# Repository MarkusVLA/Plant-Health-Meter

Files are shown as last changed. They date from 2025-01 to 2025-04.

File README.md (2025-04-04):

## Plant-health-meter
This repository contains Aalto AAN-C2009 project device hardware configuration and embedded software for a plant health monitoring system based on the ESP32c3 SoC.

## Features
- Soil moisture sensing
- Ambient light monitoring
- Temperature and humidity measurement
- Battery-powered operation with charging circuit
- Web interface for monitoring plant health 

## PCB
PCB design done in KiCad.
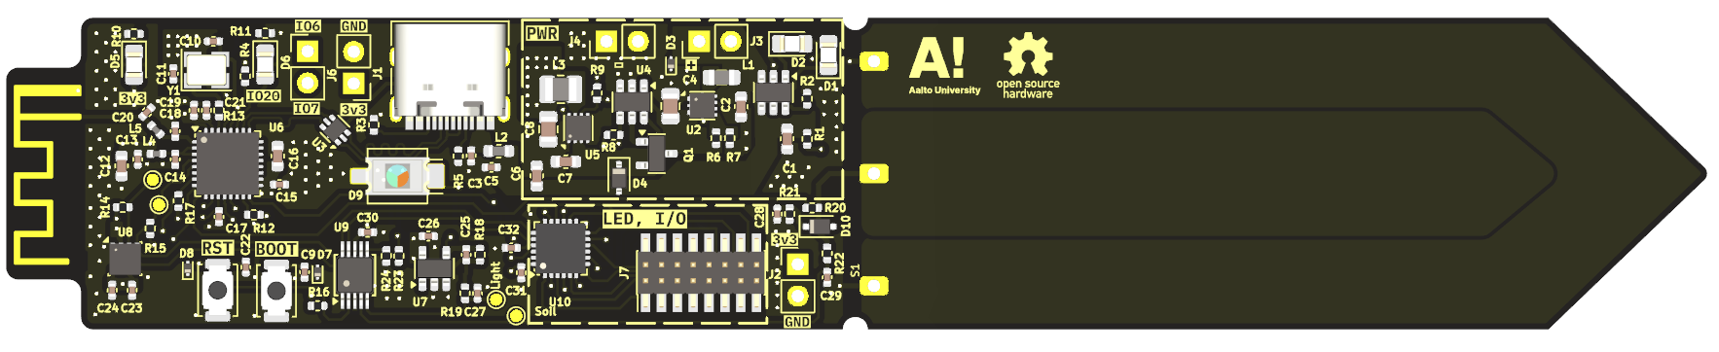
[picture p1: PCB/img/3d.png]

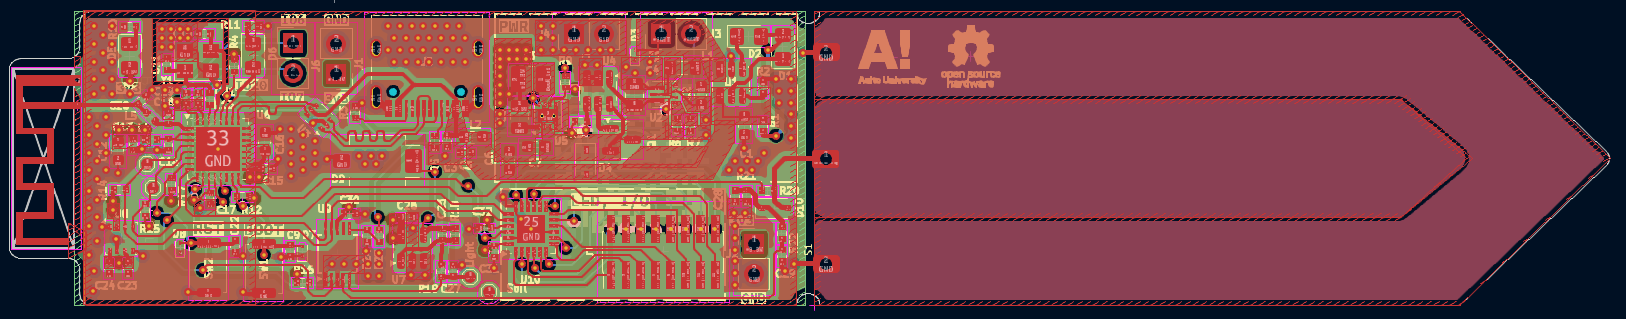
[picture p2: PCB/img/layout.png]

Schematic: [PDF](PCB/img/schematic.pdf)

## Key Components
- ESP32-C3 microcontroller
- BME280 temperature/humidity sensor
- Custom capacitive soil moisture sensor
- Photodiode and OPA340 based transimpedance amplifier
- ADS1115 16-bit ADC for accurate measurements

## Embedded software
Embedded software is written in C using the ESP-IDF (Espressif IoT Development Framework)
[ESP programming guide](https://docs.espressif.com/projects/esp-idf/en/v5.2.5/esp32c3/get-started/index.html)

## Pin Assignments
See the schematic for detailed I/O connections and sensor bus configuration.

## Setup Instructions
1. Follow the ESP-IDF installation guide
2. Clone this repository
3. In the `main/` folder create `private_config.h` file, with following definitions:
    1. `#define FIREBASE_HOST "xxx.firebasedatabase.app"` - url of the firebase realtime database
    2. `#define FIREBASE_AUTH ""` - authentication token for the firebase - (TODO: not tested yet with protected database)
4. Set ESP32-C3 target in the idf `idf.py set-target esp32c3`
5. Configure the partitions and BLE version `idf.py menuconfig`:
    1. Go to Partition Table → Partition Table and select Custom partition table CSV. Then set the path to `partitions.csv`.
    2. Go to Component Config → Bluetooth → Bluedroid BLE version and choose v4.0.
    3. Save and exit the configuration menu.
6. Build and flash using `idf.py build flash monitor`

## Connection Instructions

1. By default, there are no Wi-Fi credentials set. The device will immediately enter Bluetooth setup mode on boot.

2. For setup, you’ll need a mobile app capable of sending data over BLE, such as **nRF Connect**.

3. When the device is in Bluetooth setup mode, one of its LEDs will begin blinking. You can then find the device in the app under the name:  
   **`PLANT_SENSOR_01`**

4. Press **Connect** to establish a Bluetooth connection.

5. Once connected, look for **Advertised Services** in the device details. Find the characteristic that supports both **Read** and **Write**, and tap the **up arrow (⬆️)** to write data.

6. Select **UTF-8** as the encoding format and send a message with the following structure:  
   ```
   device_id:wifi_ssid:wifi_password
   ```

   For example:  
   ```
   sensor1:mywifi:secret_password
   ```

7. After sending the credentials, the device will restart and attempt to connect to the specified Wi-Fi network.

8. Once connected, sensor data will be sent to Firebase under the provided `device_id`.

---

**Important Notes:**
- `device_id` can contain only **letters, digits, and underscores** (e.g., `plant_sensor_1`).
- If the device fails to connect to Wi-Fi, it will re-enter Bluetooth setup mode on reboot.

## Power Requirements
3.7V Li-ion battery or USB power

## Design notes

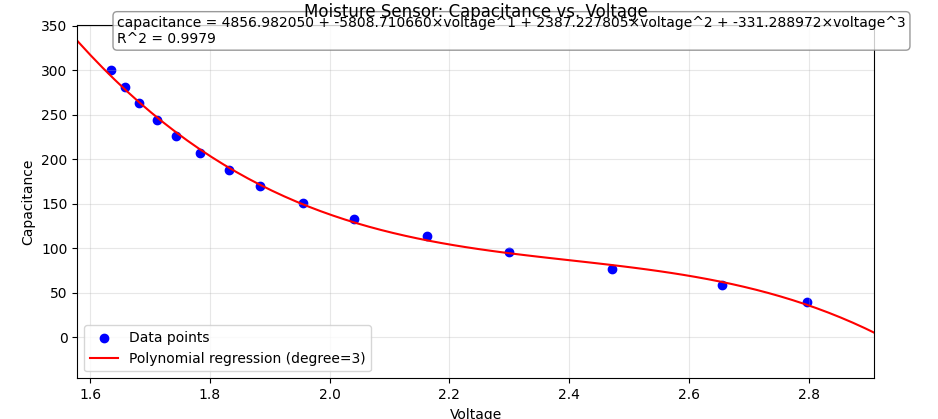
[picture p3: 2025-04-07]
documentation/img/regression.png

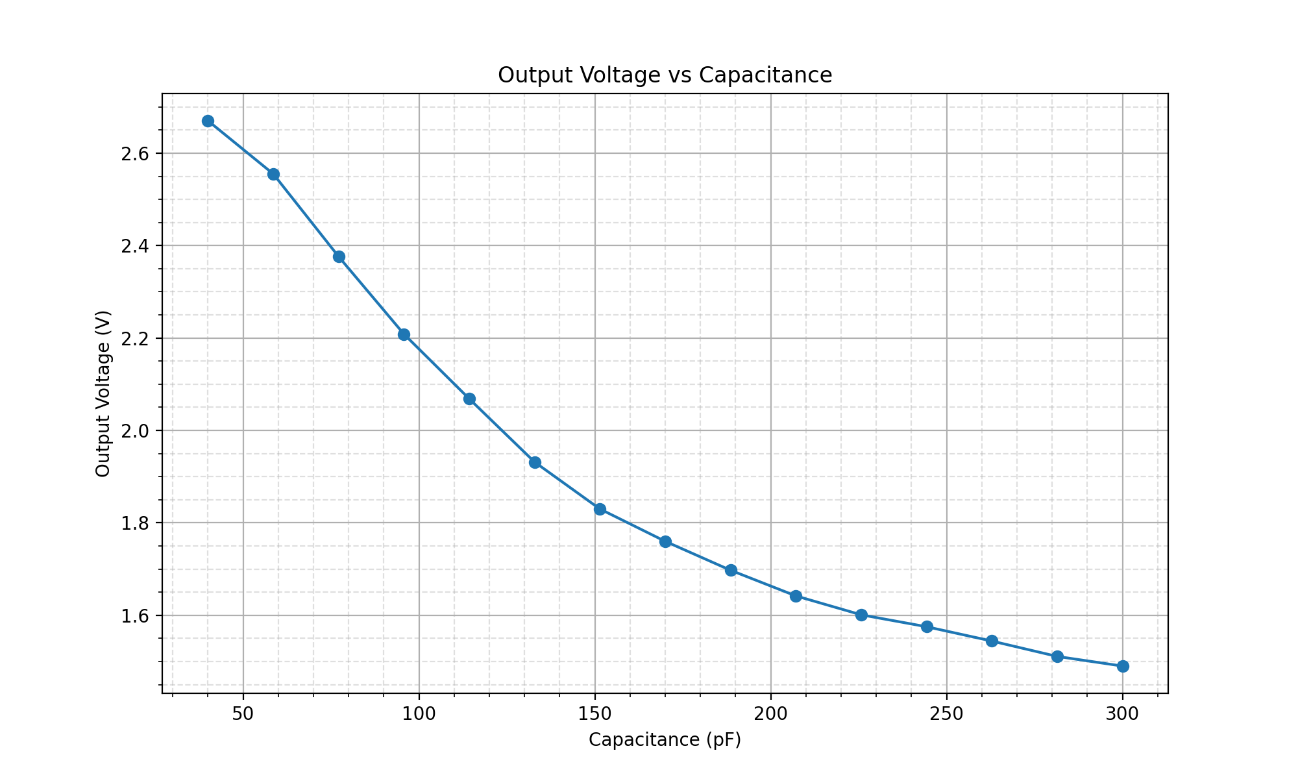
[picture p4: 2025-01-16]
simulation/Moisture_sensor/voltage_vs_capacitance.png

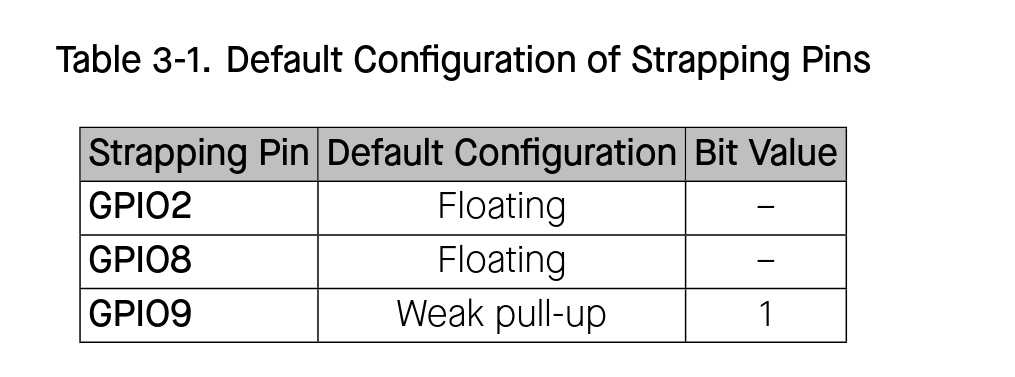
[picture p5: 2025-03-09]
PCB/Strapping_pins.png

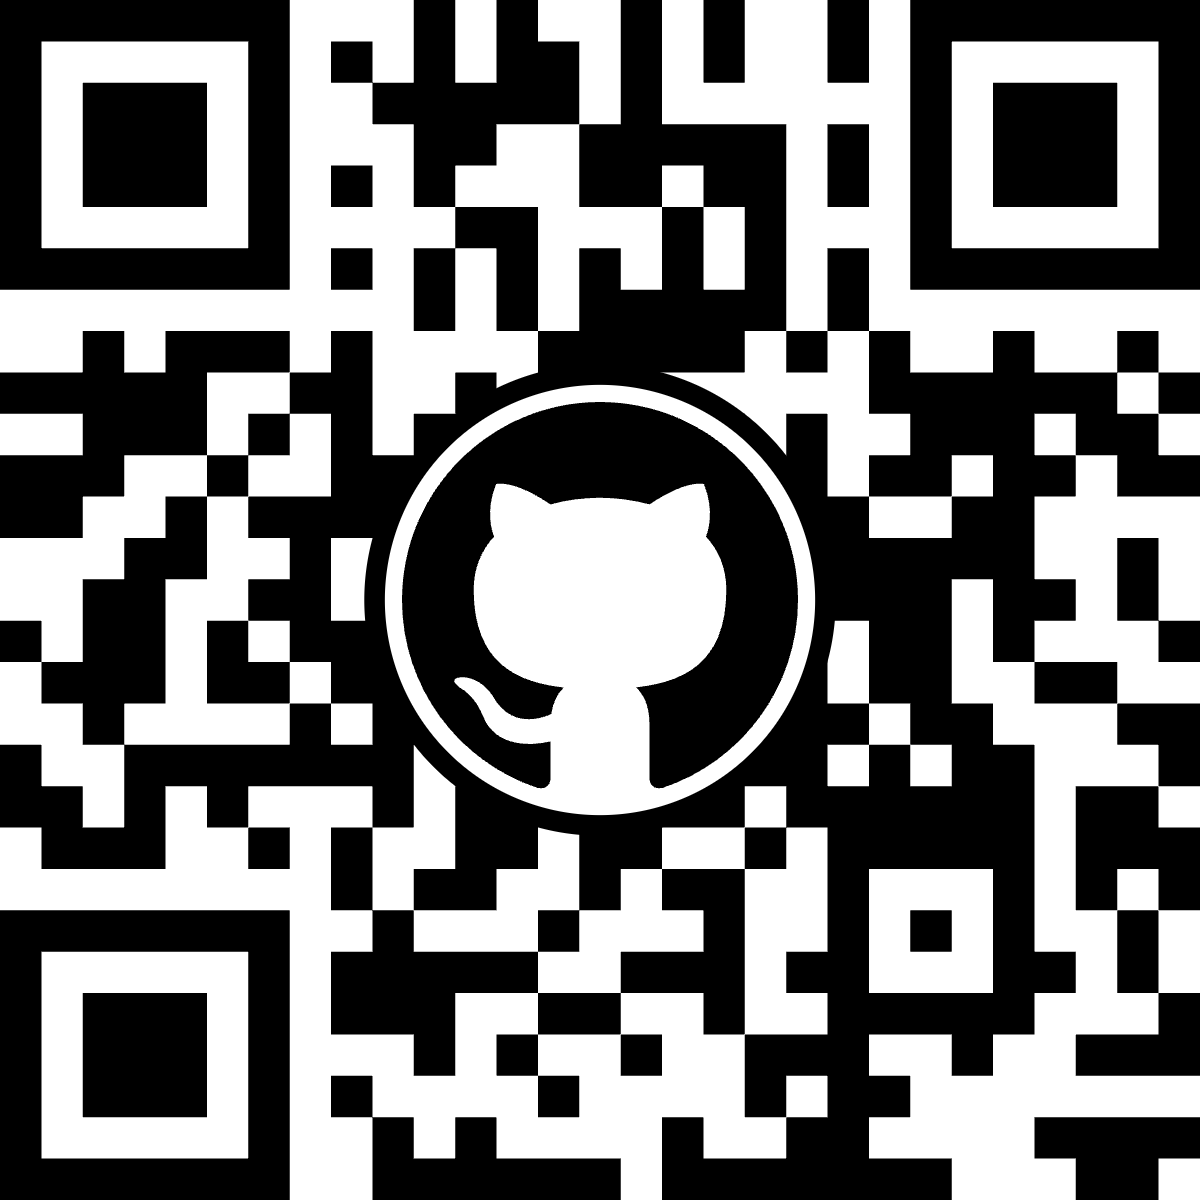
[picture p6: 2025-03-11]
PCB/silkscreen-pictures/QR-for-MarkusVLA.png

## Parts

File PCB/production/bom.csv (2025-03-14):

Designator | Footprint | Quantity | Value | LCSC Part #
AE1 | Texas_SWRA117D_2.4GHz_Left | 1 | Antenna_Shield
C1, C12, C16, C2, C6, C7 | 0603 | 6 | 10u
C10, C11 | 0402 | 2 | 15p
C13, C14, C15, C17, C19, C21, C22, C23, C24, C26, C27, C29, C3, C30, C31, C32, C5, C9 | 0402 | 18 | 100n
C18, C20 | 0402 | 2 | 2.2p
C25 | 0402 | 1 | 220n
C28 | 0402 | 1 | 1n
C4, C8 | 0805 | 2 | 22u
D1, D2, D5, D6 | 0805 | 4 | LED | C205445
D10 | D_SOD-323F | 1 | BAT54J
D3, D7, D8 | D_SOD-923 | 3 | ESD9B5.0ST5G
D4 | D_SOD-323 | 1 | BAT60A
D9 | Osram_BPW34S-SMD | 1 | BPW34-SMD
J1, J2, J3, J4, J6 | PinHeader_1x02_P2.54mm_Vertical | 5 | Conn_01x02
J5 | USB_C_Receptacle_HRO_TYPE-C-31-M-12 | 1 | USB_C_Receptacle_USB2.0_14P
J7 | PinHeader_2x08_P1.27mm_Vertical_SMD | 1 | Conn_02x08_Counter_Clockwise
L1 | 0805 | 1 | 1u
L2 | 0603 | 1 | 2.2n
L3 | 1008 | 1 | 2.2u
L4 | 0402 | 1 | 2.2n
L5 | 0402 | 1 | 2.6n
Q1 | SOT-23 | 1 | AO3401A
R1 | 0402 | 1 | 1k
R10, R11 | 0402 | 2 | 1k
R12, R14, R15, R16, R17, R2, R3, R5 | 0402 | 8 | 5.1k
R13 | 0402 | 1 | 10
R18 | 0402 | 1 | 33k
R19, R22 | 0402 | 2 | 510
R20, R4 | 0402 | 2 | 10k
R21 | 0402 | 1 | 1M
R23, R24, R7, R9 | 0402 | 4 | 100k
R6 | 0402 | 1 | 570k
R8 | 0402 | 1 | 470k
S1 | Moisture_sensor_pads | 1 | ~
SW1 | SW_Push_SPST_NO_Alps_SKRK | 1 | Boot | C115357
SW2 | SW_Push_SPST_NO_Alps_SKRK | 1 | Reset | C115357
TP1, TP2, TP3, TP4 | TestPoint_Pad_D1.0mm | 4 | TestPoint
U1 | TSOT-23-6 | 1 | TP4057
U10 | WQFN-24-1EP_4x4mm_P0.5mm_EP2.45x2.45mm | 1 | TCA9555RTWR
U2 | Texas_RWU0007A_VQFN-7_2x2mm_P0.5mm | 1 | TPS61022
U3 | SOT-666 | 1 | USBLC6-2P6
U4 | TSOT-23-6 | 1 | LTC4412xS6
U5 | WSON-8-1EP_2x2mm_P0.5mm_EP0.9x1.6mm_ThermalVias | 1 | TPS62172DSG
U6 | QFN-32-1EP_5x5mm_P0.5mm_EP3.7x3.7mm | 1 | ESP32-C3FH4X
U7 | SOT-23-5 | 1 | OPA340NA
U8 | Bosch_LGA-8_2.5x2.5mm_P0.65mm_ClockwisePinNumbering | 1 | BME280
U9 | TSSOP-10_3x3mm_P0.5mm | 1 | ADS1115IDGS
Y1 | Crystal_SMD_3225-4Pin_3.2x2.5mm | 1 | 40MHz

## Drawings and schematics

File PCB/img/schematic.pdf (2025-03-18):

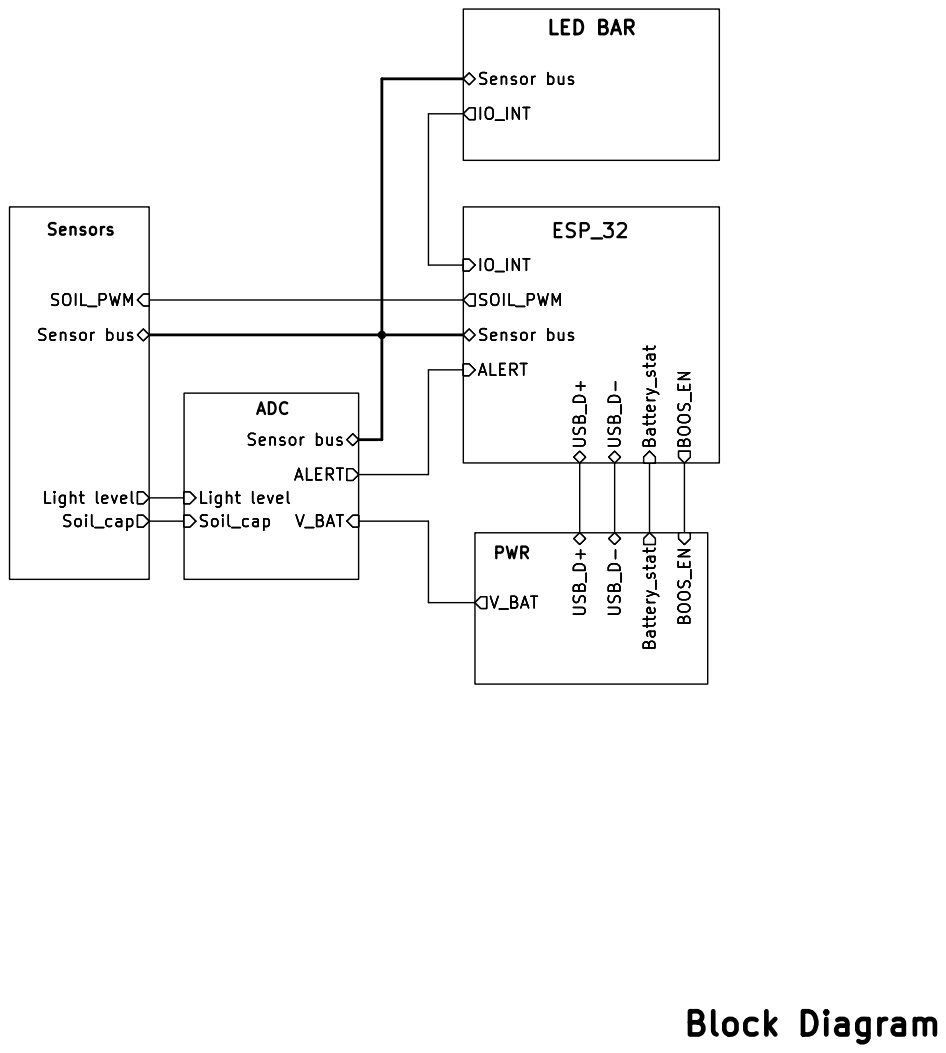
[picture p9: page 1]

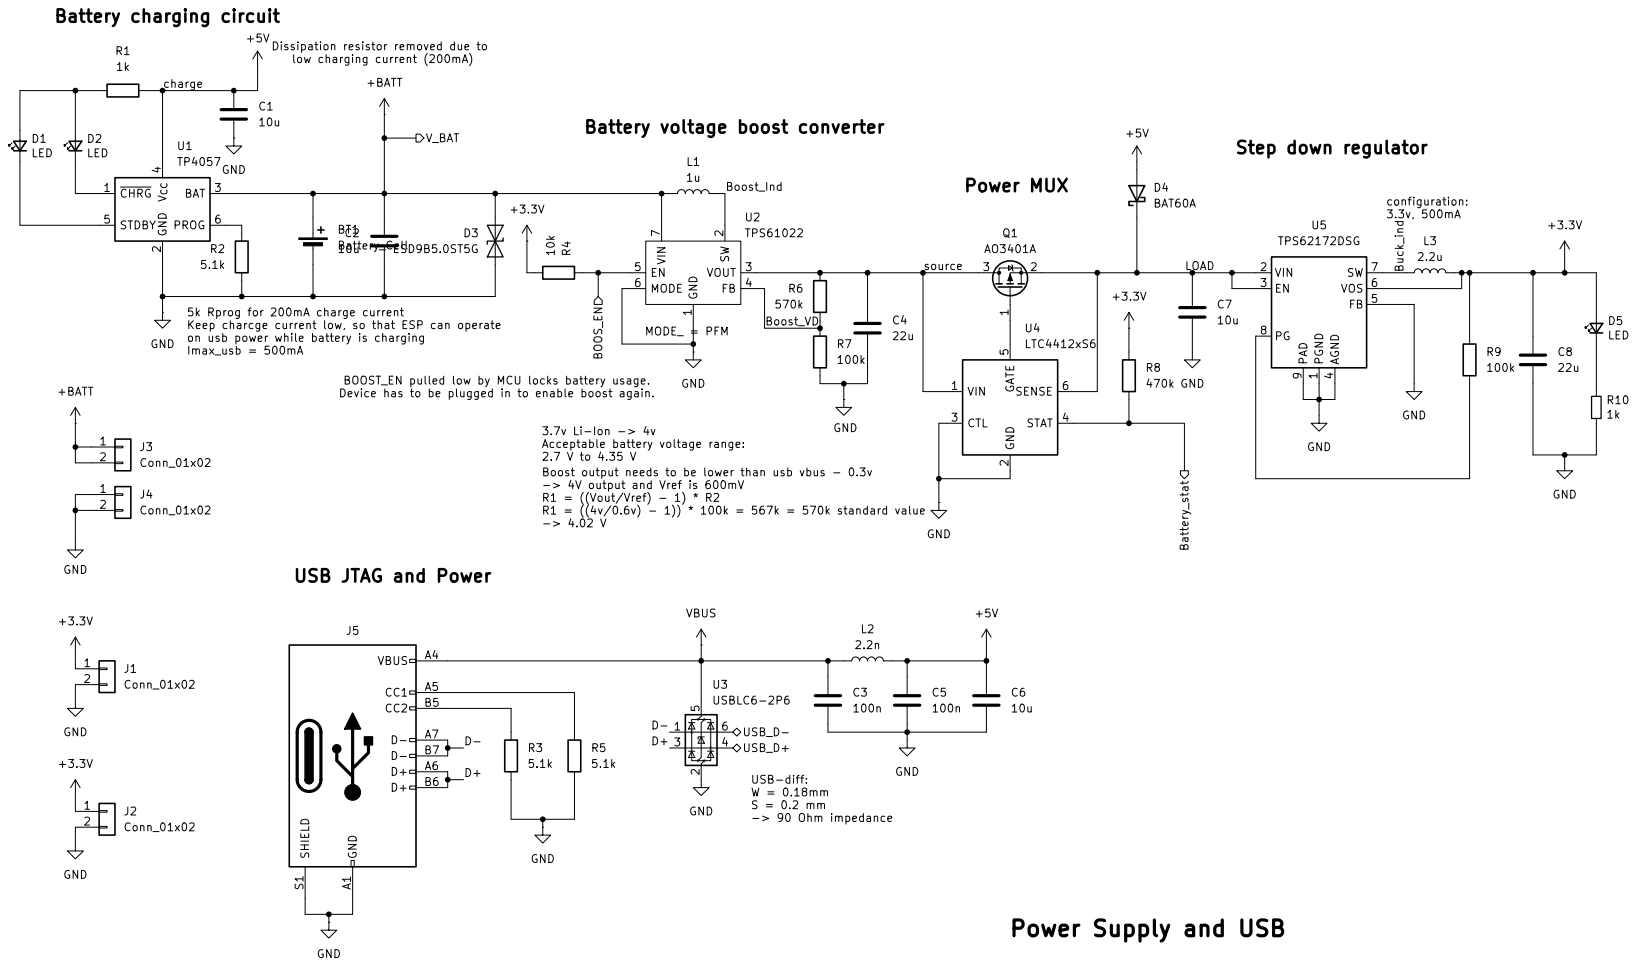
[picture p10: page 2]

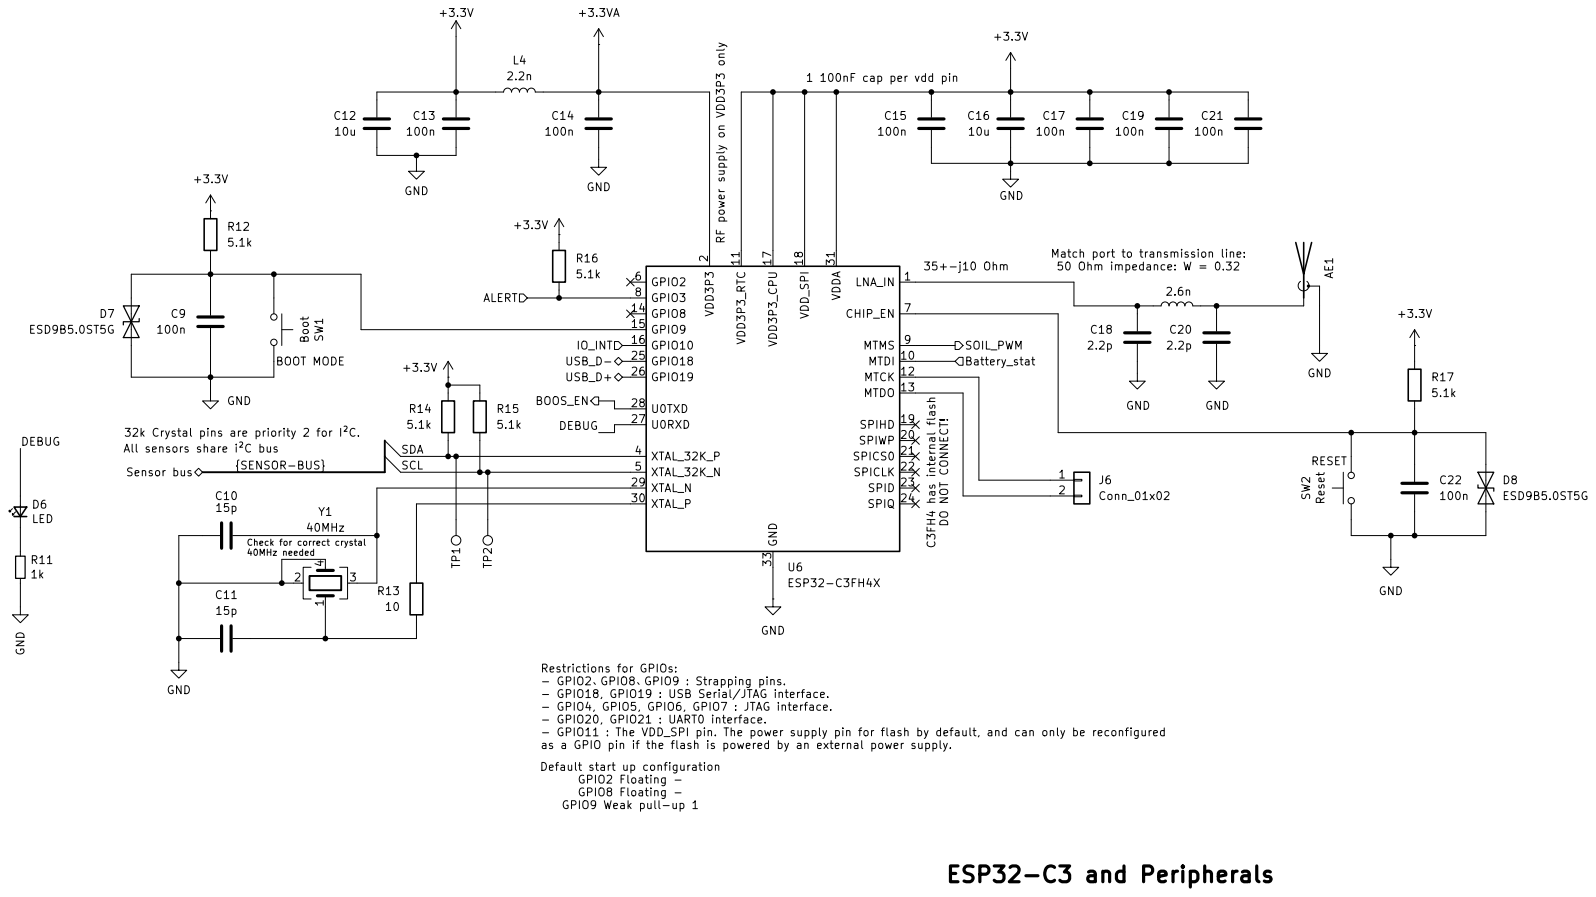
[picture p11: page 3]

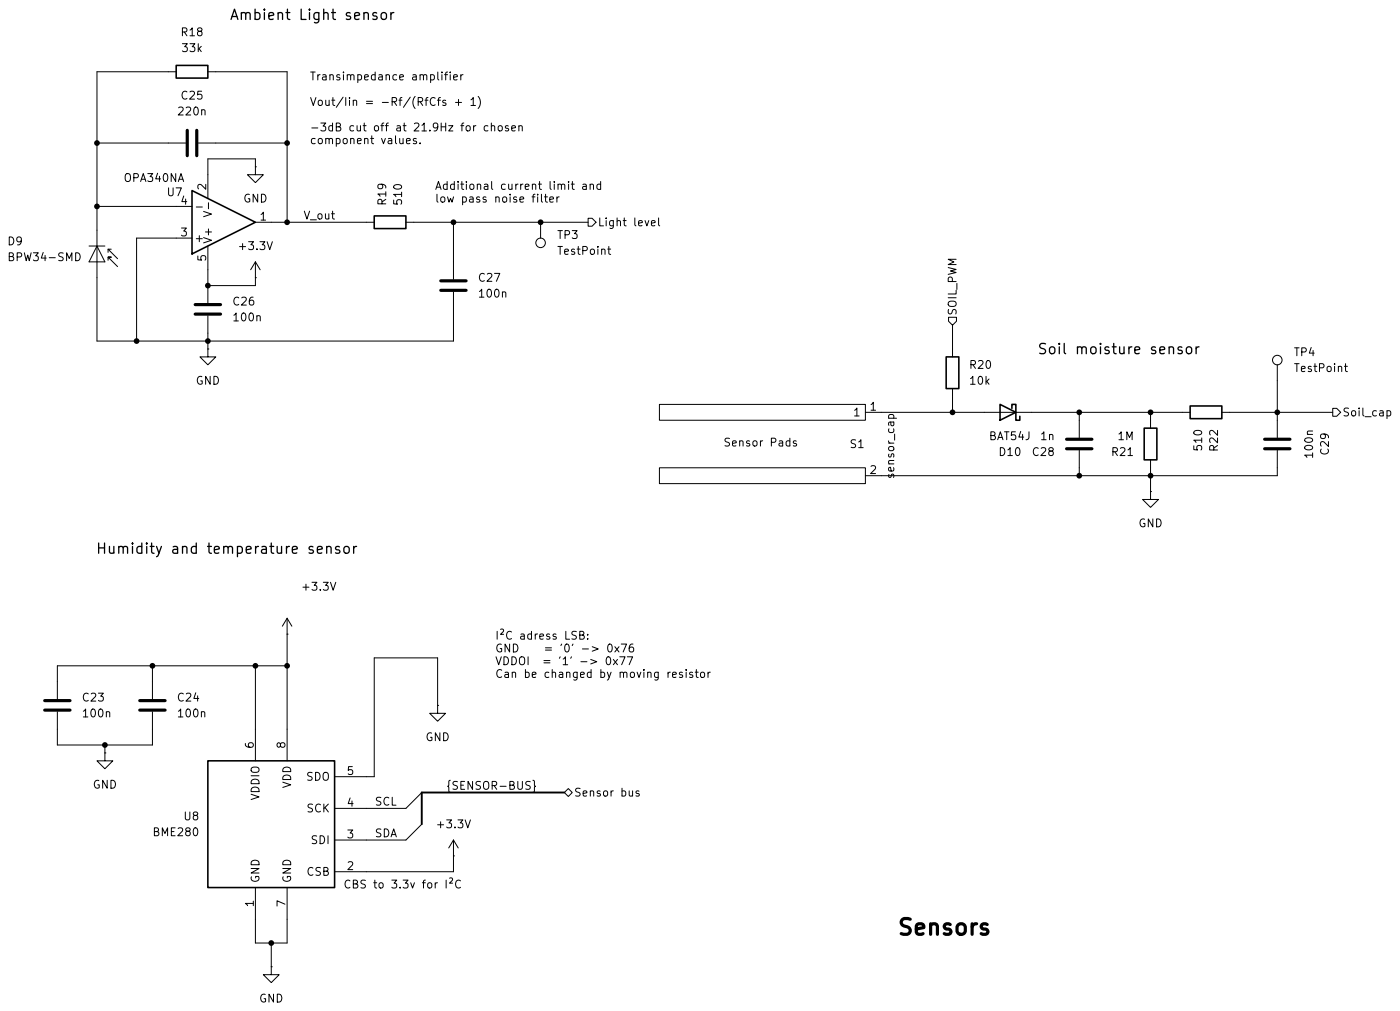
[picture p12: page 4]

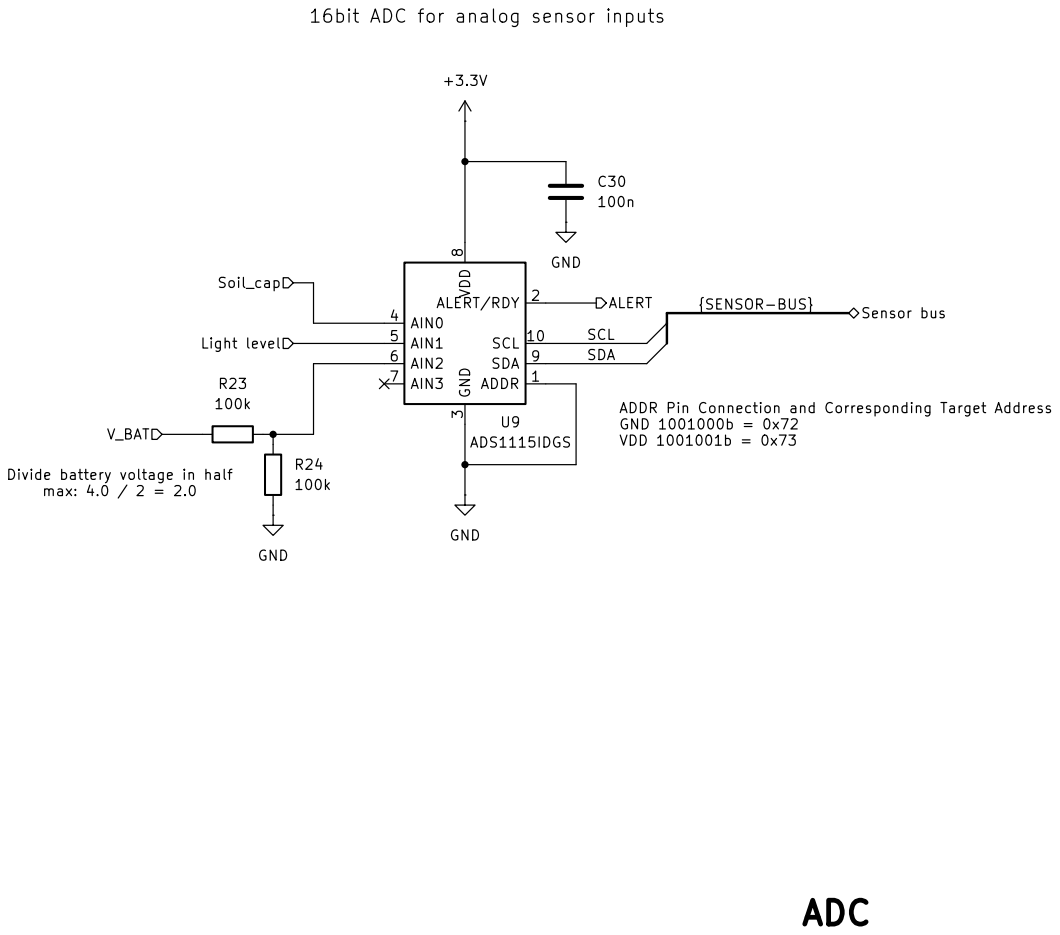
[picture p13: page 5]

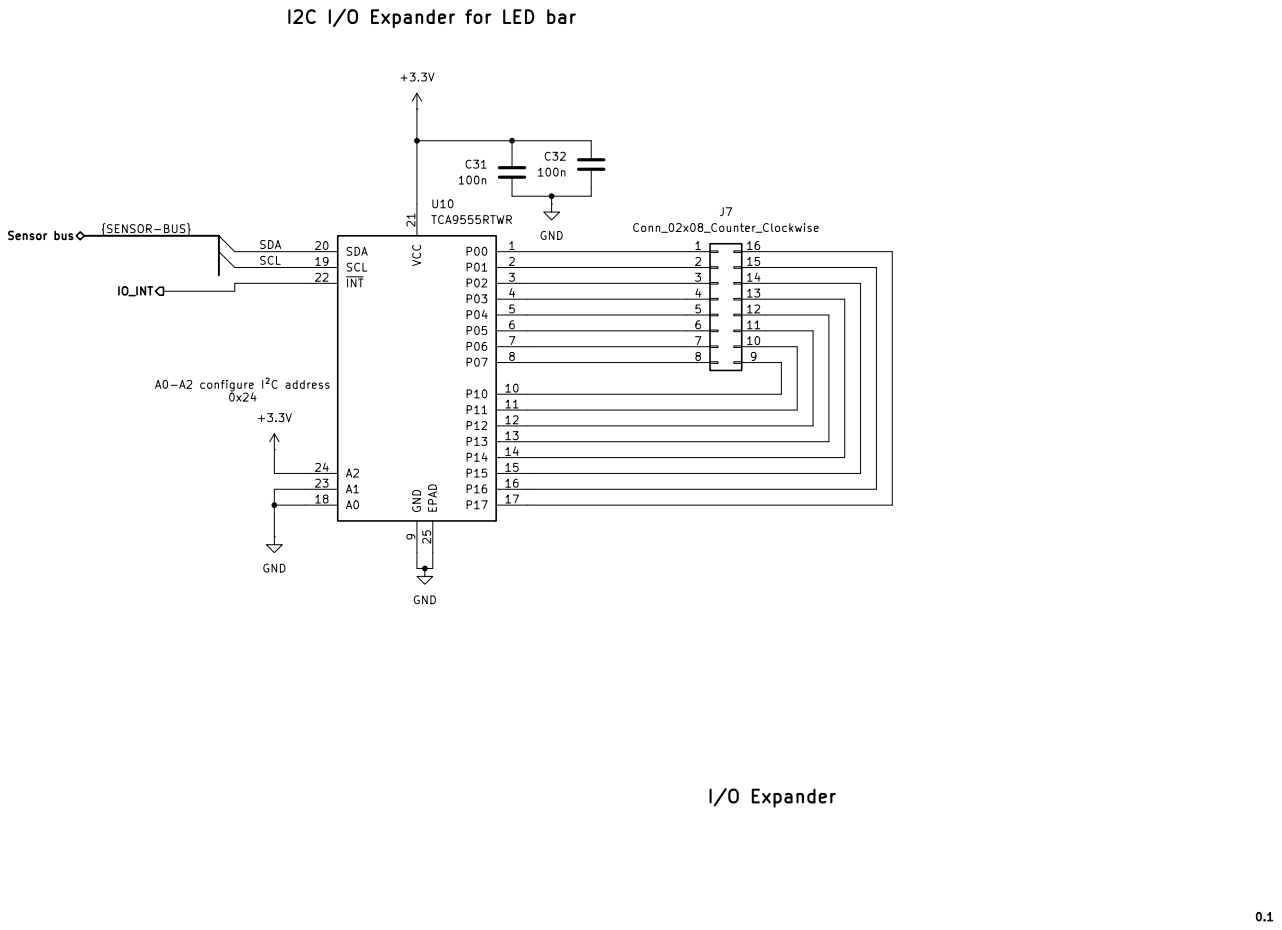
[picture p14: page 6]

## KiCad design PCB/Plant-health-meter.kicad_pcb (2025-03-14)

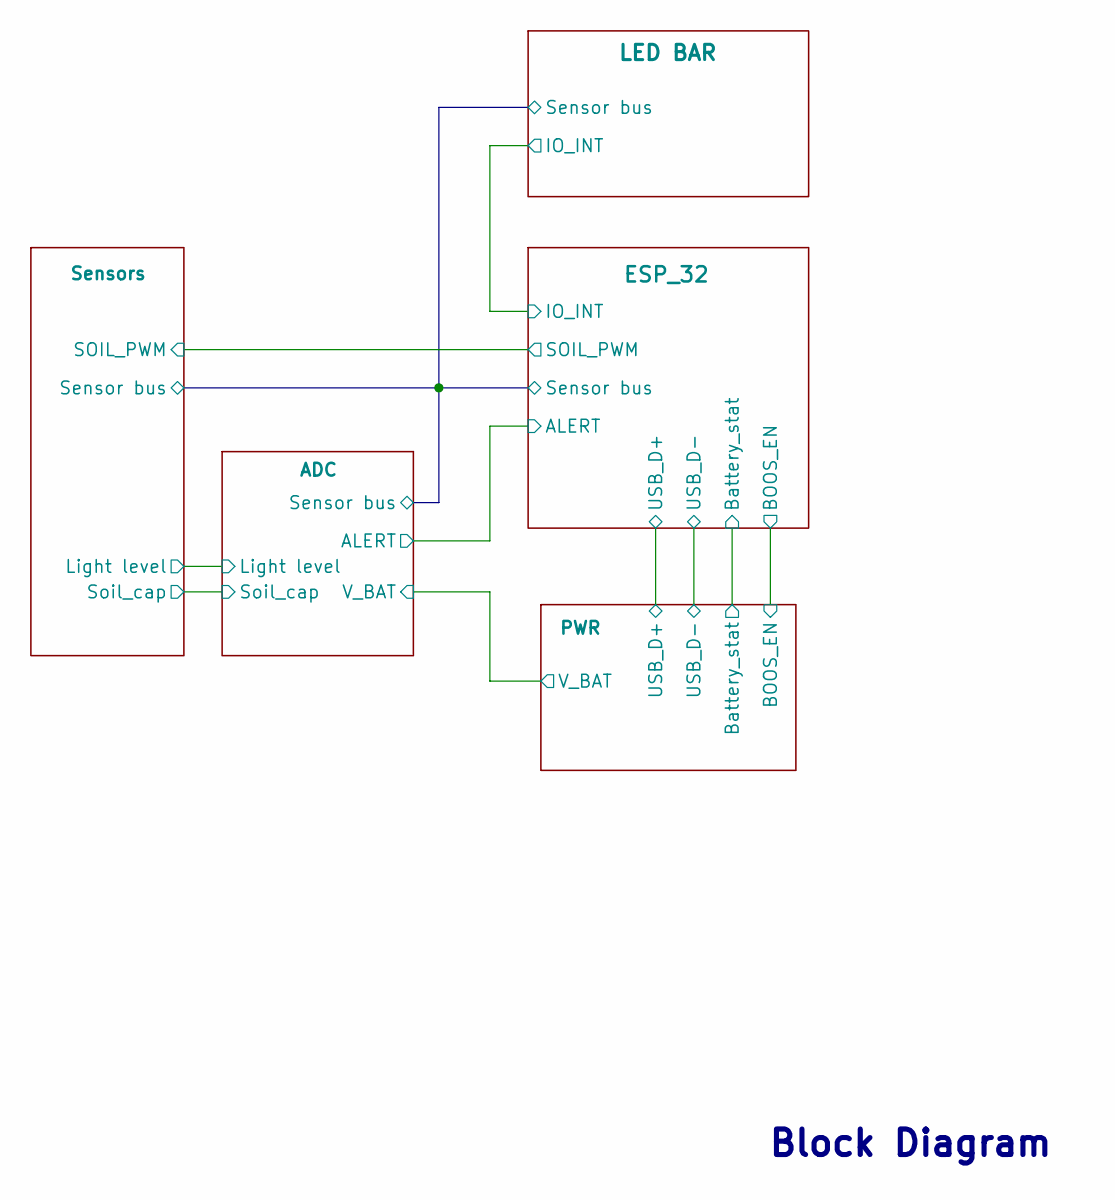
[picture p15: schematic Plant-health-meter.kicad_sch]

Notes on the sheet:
Block Diagram

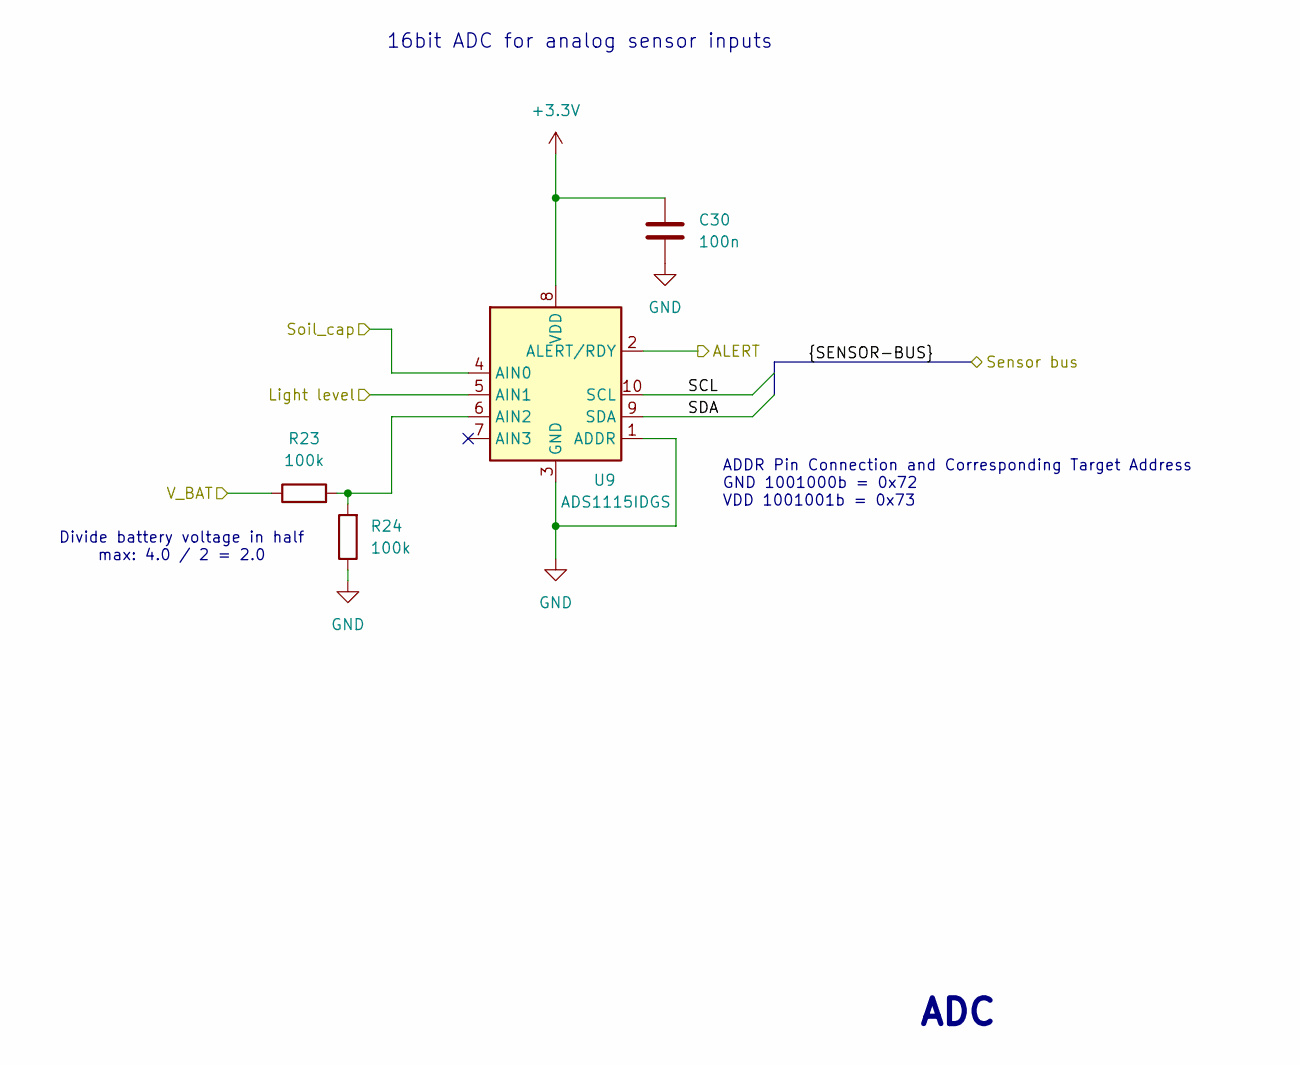
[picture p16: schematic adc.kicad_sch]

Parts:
C30: 100n; C_0402_1005Metric
R23, R24: 100k; R_0402_1005Metric
U9: ADS1115IDGS; TSSOP-10_3x3mm_P0.5mm

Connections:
+3.3V: C30.1, U9.8 (VDD); also elsewhere on the board
+BATT: R23.1; also elsewhere on the board
/ADC/ALERT: U9.2 (ALERT/RDY); also elsewhere on the board
/ADC/Light level: U9.5 (AIN1); also elsewhere on the board
/ADC/SCL: U9.10 (SCL); also elsewhere on the board
/ADC/SDA: U9.9 (SDA); also elsewhere on the board
/ADC/Soil_cap: U9.4 (AIN0); also elsewhere on the board
GND: C30.2, R24.1, U9.1 (ADDR), U9.3 (GND); also elsewhere on the board
unnamed: R23.2, R24.2, U9.6 (AIN2)

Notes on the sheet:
ADDR Pin Connection and Corresponding Target Address GND 1001000b = 0x72 VDD 1001001b = 0x73
Divide battery voltage in half max: 4.0 / 2 = 2.0
16bit ADC for analog sensor inputs
ADC

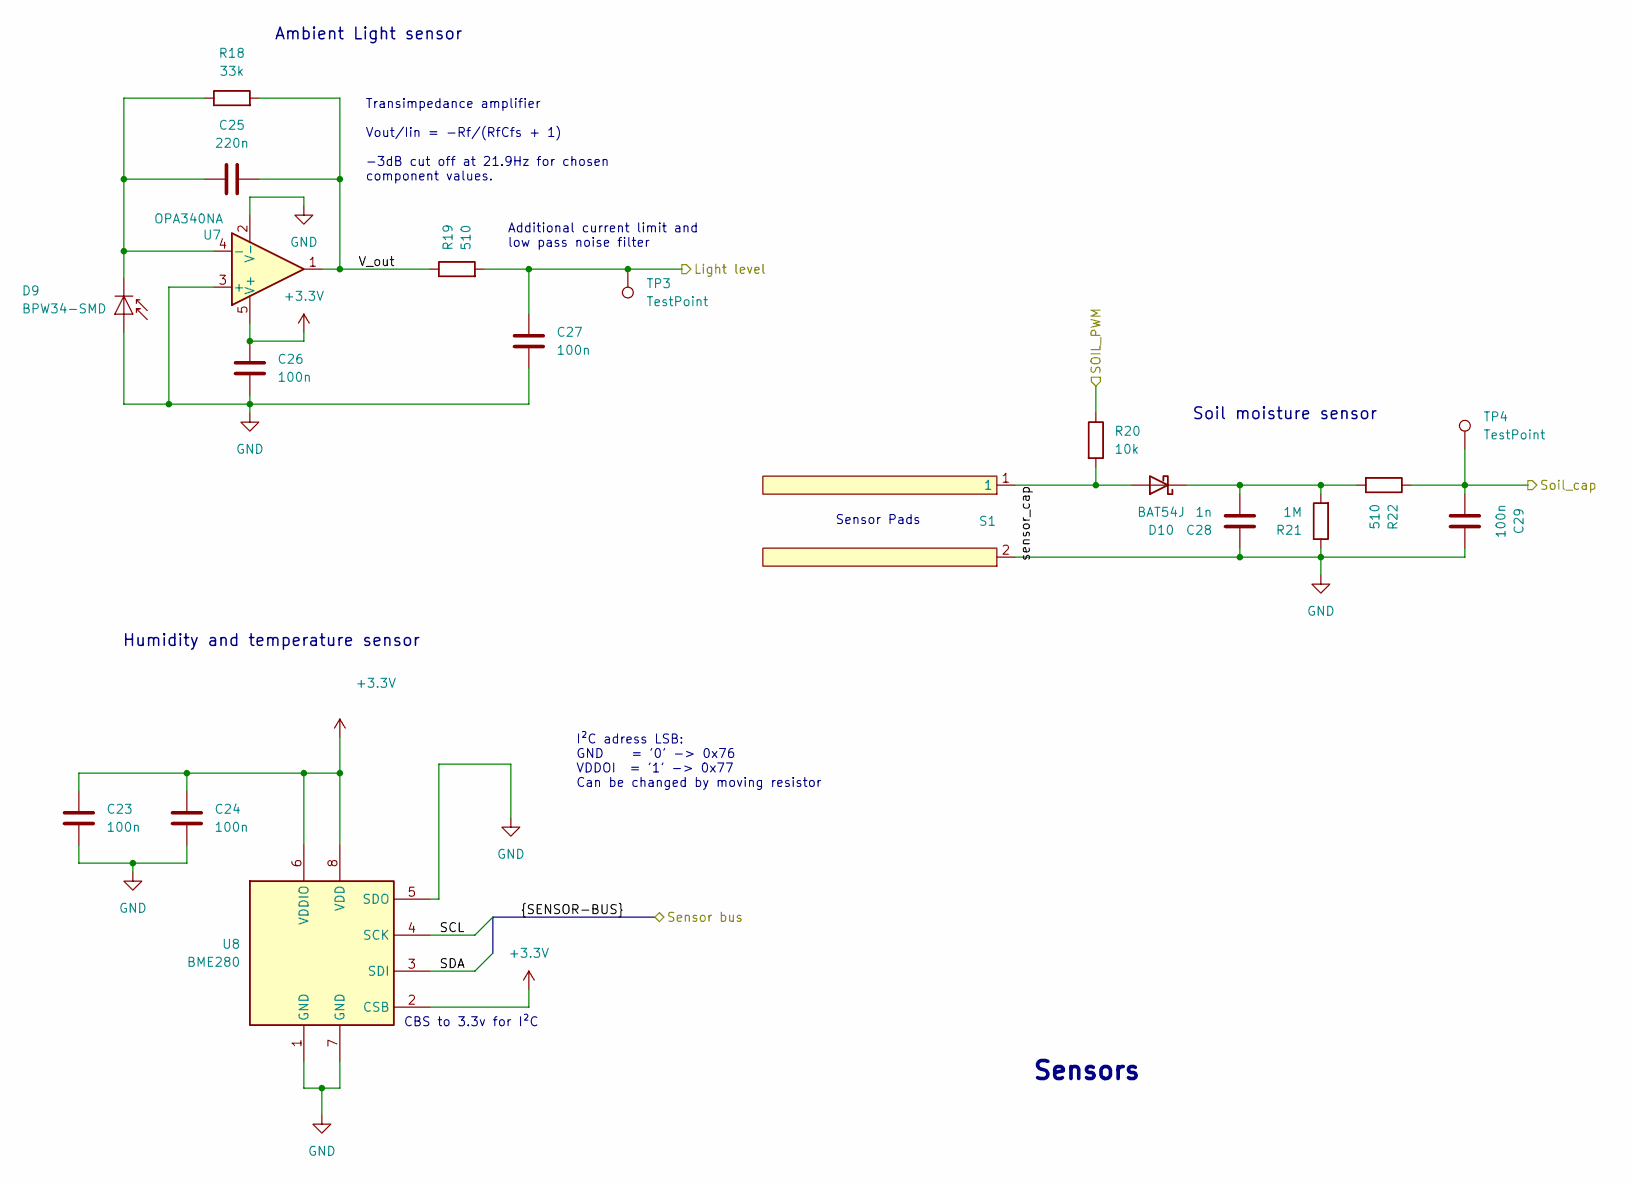
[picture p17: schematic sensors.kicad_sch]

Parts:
C23, C24, C26, C27, C29: 100n; C_0402_1005Metric
C25: 220n; C_0402_1005Metric
C28: 1n; C_0402_1005Metric
D9: BPW34-SMD; Osram_BPW34S-SMD
D10: BAT54J; D_SOD-323F
R18: 33k; R_0402_1005Metric
R19, R22: 510; R_0402_1005Metric
R20: 10k; R_0402_1005Metric
R21: 1M; R_0402_1005Metric
S1: Moisture_sensor_pads
TP3, TP4: TestPoint; TestPoint_Pad_D1.0mm
U7: OPA340NA; SOT-23-5
U8: BME280; Bosch_LGA-8_2.5x2.5mm_P0.65mm_ClockwisePinNumbering

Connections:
+3.3V: C23.1, C24.1, C26.1, U7.5 (V+), U8.2 (CSB), U8.6 (VDDIO), U8.8 (VDD); also elsewhere on the board
/ADC/Light level: C27.1, R19.2, TP3.1; also elsewhere on the board
/ADC/SCL: U8.4 (SCK); also elsewhere on the board
/ADC/SDA: U8.3 (SDI); also elsewhere on the board
/ADC/Soil_cap: C29.1, R22.1, TP4.1; also elsewhere on the board
/ESP_32/SOIL_PWM: R20.1; also elsewhere on the board
/Sensors/V_out: C25.2, R18.2, R19.1, U7.1
/Sensors/sensor_cap: D10.2 (A), R20.2, S1.1
GND: C23.2, C24.2, C26.2, C27.2, C28.1, C29.2, D9.2 (A), R21.1, S1.2, U7.2 (V-), U7.3 (+), U8.1 (GND), U8.5 (SDO), U8.7 (GND); also elsewhere on the board
unnamed: C25.1, D9.1 (K), R18.1, U7.4 (-)
unnamed: C28.2, D10.1 (K), R21.2, R22.2

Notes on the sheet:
CBS to 3.3v for I²C
Sensor Pads
I²C adress LSB: GND = '0' -> 0x76 VDDOI = '1' -> 0x77 Can be changed by moving resistor
Soil moisture sensor
Additional current limit and low pass noise filter
Transimpedance amplifier Vout/Iin = -Rf/(RfCfs + 1) -3dB cut off at 21.9Hz for chosen component values.
Humidity and temperature sensor
Sensors
Ambient Light sensor

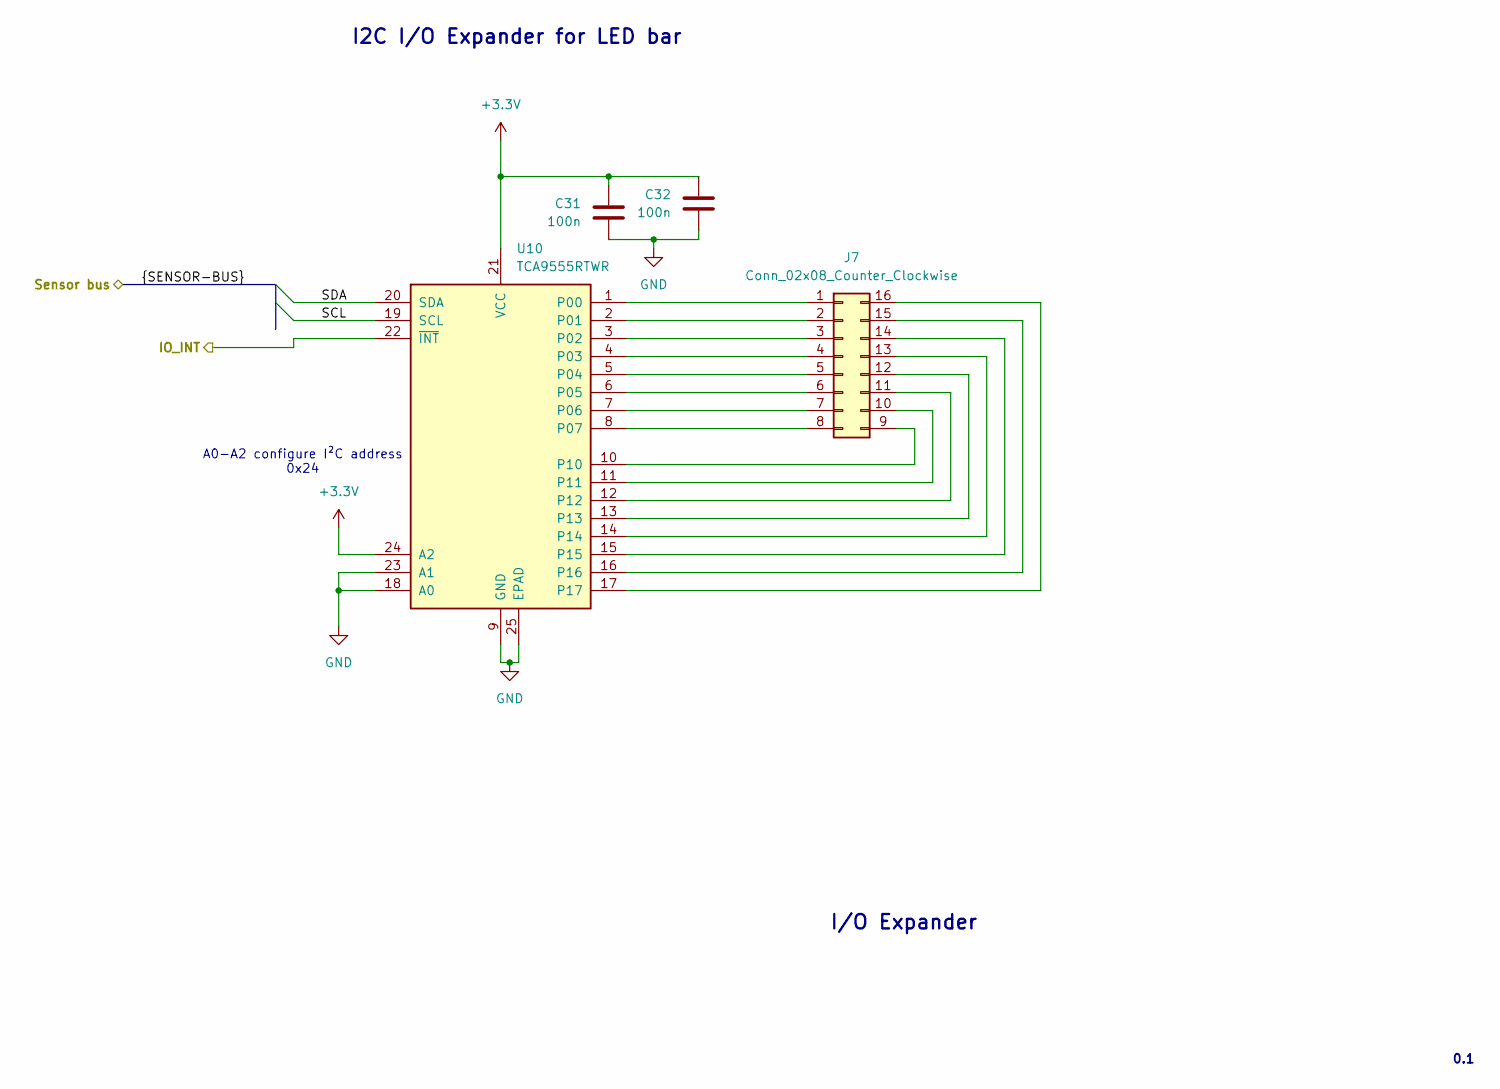
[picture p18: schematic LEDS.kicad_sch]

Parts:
C31, C32: 100n; C_0402_1005Metric
J7: Conn_02x08_Counter_Clockwise; PinHeader_2x08_P1.27mm_Vertical_SMD
U10: TCA9555RTWR; WQFN-24-1EP_4x4mm_P0.5mm_EP2.45x2.45mm

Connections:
+3.3V: C31.1, C32.1, U10.21 (VCC), U10.24 (A2); also elsewhere on the board
/ADC/SCL: U10.19 (SCL); also elsewhere on the board
/ADC/SDA: U10.20 (SDA); also elsewhere on the board
/ESP_32/IO_INT: U10.22 (~INT); also elsewhere on the board
GND: C31.2, C32.2, U10.9 (GND), U10.18 (A0), U10.23 (A1), U10.25 (EPAD); also elsewhere on the board
unnamed: J7.1, U10.1 (P00)
unnamed: J7.2, U10.2 (P01)
unnamed: J7.3, U10.3 (P02)
unnamed: J7.4, U10.4 (P03)
unnamed: J7.5, U10.5 (P04)
unnamed: J7.6, U10.6 (P05)
unnamed: J7.7, U10.7 (P06)
unnamed: J7.8, U10.8 (P07)
unnamed: J7.9, U10.10
unnamed: J7.10, U10.11
unnamed: J7.11, U10.12
unnamed: J7.12, U10.13
unnamed: J7.13, U10.14
unnamed: J7.14, U10.15
unnamed: J7.15, U10.16
unnamed: J7.16, U10.17

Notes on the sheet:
0.1
I2C I/O Expander for LED bar
A0-A2 configure I²C address 0x24
I/O Expander

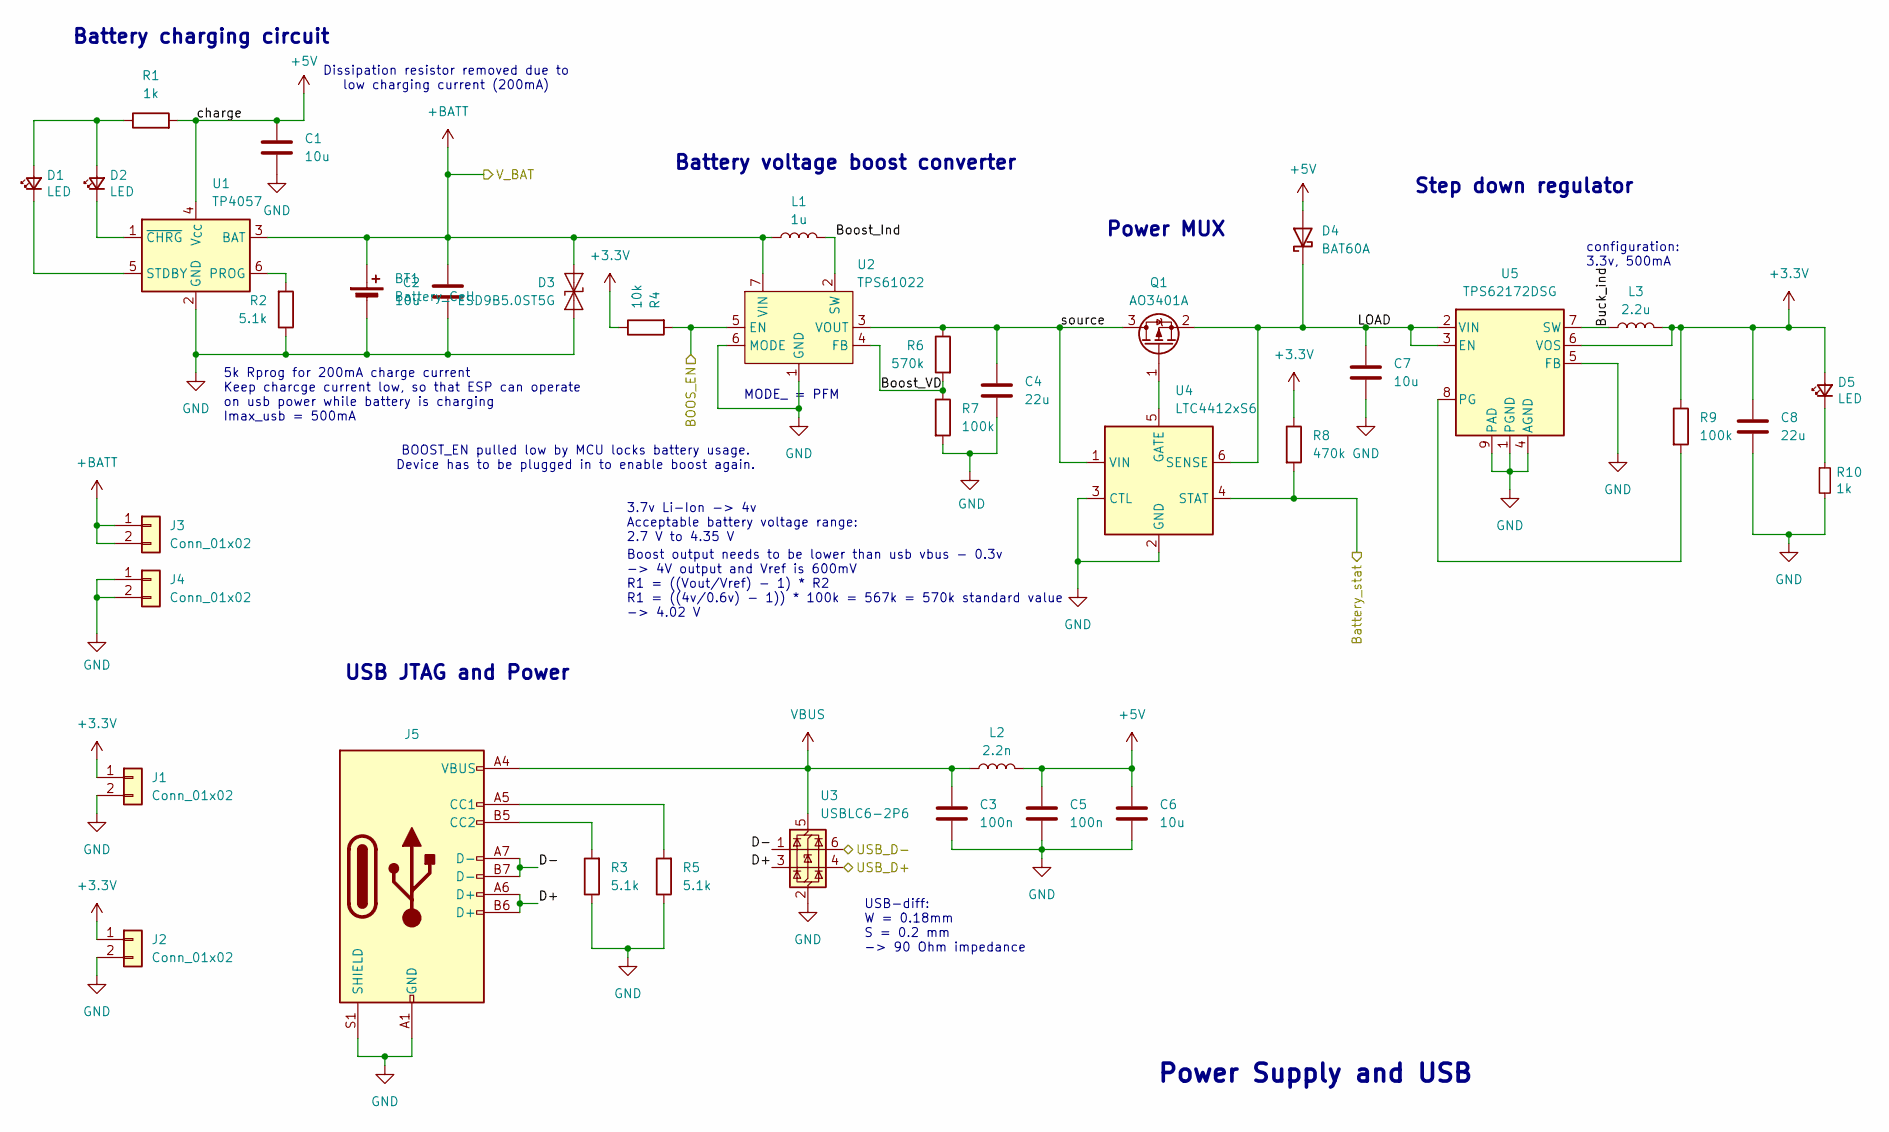
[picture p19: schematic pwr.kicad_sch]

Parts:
BT1: Battery_Cell
C1, C2, C6, C7: 10u; C_0603_1608Metric
C3, C5: 100n; C_0402_1005Metric
C4, C8: 22u; C_0805_2012Metric
D1, D2, D5: LED; LED_0805_2012Metric_Pad1.15x1.40mm_HandSolder; LCSC C205445
D3: ESD9B5.0ST5G; D_SOD-923
D4: BAT60A; D_SOD-323
J1, J2, J3, J4: Conn_01x02; PinHeader_1x02_P2.54mm_Vertical
J5: USB_C_Receptacle_USB2.0_14P; USB_C_Receptacle_HRO_TYPE-C-31-M-12
L1: 1u; L_0805_2012Metric
L2: 2.2n; L_0603_1608Metric
L3: 2.2u; L_1008_2520Metric
Q1: AO3401A; SOT-23
R1, R10: 1k; R_0402_1005Metric
R2, R3, R5: 5.1k; R_0402_1005Metric
R4: 10k; R_0402_1005Metric
R6: 570k; R_0402_1005Metric
R7, R9: 100k; R_0402_1005Metric
R8: 470k; R_0402_1005Metric
U1: TP4057; TSOT-23-6
U2: TPS61022; Texas_RWU0007A_VQFN-7_2x2mm_P0.5mm
U3: USBLC6-2P6; SOT-666
U4: LTC4412xS6; TSOT-23-6
U5: TPS62172DSG; WSON-8-1EP_2x2mm_P0.5mm_EP0.9x1.6mm_ThermalVias

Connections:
+3.3V: C8.1, D5.2 (A), J1.1, J2.1, L3.2, R4.1, R8.1, R9.1, U5.6 (VOS); also elsewhere on the board
+5V: C1.1, C5.1, C6.1, D4.2 (A), L2.2, R1.2, U1.4 (V_{CC})
+BATT: BT1.1 (+), C2.1, D3.2 (A2), J3.1, J3.2, L1.1, U1.3 (BAT), U2.7 (VIN); also elsewhere on the board
/ESP_32/BOOS_EN: R4.2, U2.5 (EN); also elsewhere on the board
/ESP_32/Battery_stat: R8.2, U4.4 (STAT); also elsewhere on the board
/ESP_32/USB_D+: U3.4 (I/O2); also elsewhere on the board
/ESP_32/USB_D-: U3.6 (I/O1); also elsewhere on the board
/PWR/Boost_Ind: L1.2, U2.2 (SW)
/PWR/Boost_VD: R6.2, R7.1, U2.4 (FB)
/PWR/Buck_ind: L3.1, U5.7 (SW)
/PWR/D+: J5.A6 (D+), J5.B6 (D+), U3.3 (I/O2)
/PWR/D-: J5.A7 (D-), J5.B7 (D-), U3.1 (I/O1)
/PWR/LOAD: C7.1, D4.1 (K), Q1.2 (S), U4.6 (SENSE), U5.2 (VIN), U5.3 (EN)
/PWR/source: C4.1, Q1.3 (D), R6.1, U2.3 (VOUT), U4.1 (VIN)
GND: BT1.2 (-), C1.2, C2.2, C3.2, C4.2, C5.2, C6.2, C7.2, C8.2, D3.1 (A1), J1.2, J2.2, J4.1, J4.2, J5.A1 (GND), J5.A12 (GND), J5.B1 (GND), J5.B12 (GND), J5.S1 (SHIELD), R2.1, R3.1, R5.1, R7.2, R10.2, U1.2 (GND), U2.1 (GND), U2.6 (MODE), U3.2 (GND), U4.2 (GND), U4.3 (CTL), U5.1 (PGND), U5.4 (AGND), U5.5 (FB), U5.9 (PAD); also elsewhere on the board
unnamed: D1.2 (A), D2.2 (A), R1.1
unnamed: D1.1 (K), U1.5 (STDBY)
unnamed: D2.1 (K), U1.1 (~CHRG)
unnamed: D5.1 (K), R10.1
unnamed: J5.A5 (CC1), R5.2
unnamed: J5.B5 (CC2), R3.2
unnamed: Q1.1 (G), U4.5 (GATE)
unnamed: R2.2, U1.6 (PROG)
unnamed: R9.2, U5.8 (PG)
VBUS: C3.1, J5.A4 (VBUS), J5.A9 (VBUS), J5.B4 (VBUS), J5.B9 (VBUS), L2.1, U3.5 (VBUS)

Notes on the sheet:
configuration: 3.3v, 500mA
MODE_ = PFM
Power MUX
Dissipation resistor removed due to low charging current (200mA)
BOOST_EN pulled low by MCU locks battery usage. Device has to be plugged in to enable boost again.
5k Rprog for 200mA charge current Keep charcge current low, so that ESP can operate on usb power while battery is charging Imax_usb = 500mA
Battery charging circuit
USB JTAG and Power
USB-diff: W = 0.18mm S = 0.2 mm -> 90 Ohm impedance
Boost output needs to be lower than usb vbus - 0.3v -> 4V output and Vref is 600mV R1 = ((Vout/Vref) - 1) * R2 R1 = ((4v/0.6v) - 1)) * 100k = 567k = 570k standard value -> 4.02 V
Battery voltage boost converter
3.7v Li-Ion -> 4v Acceptable battery voltage range: 2.7 V to 4.35 V
Step down regulator
Power Supply and USB

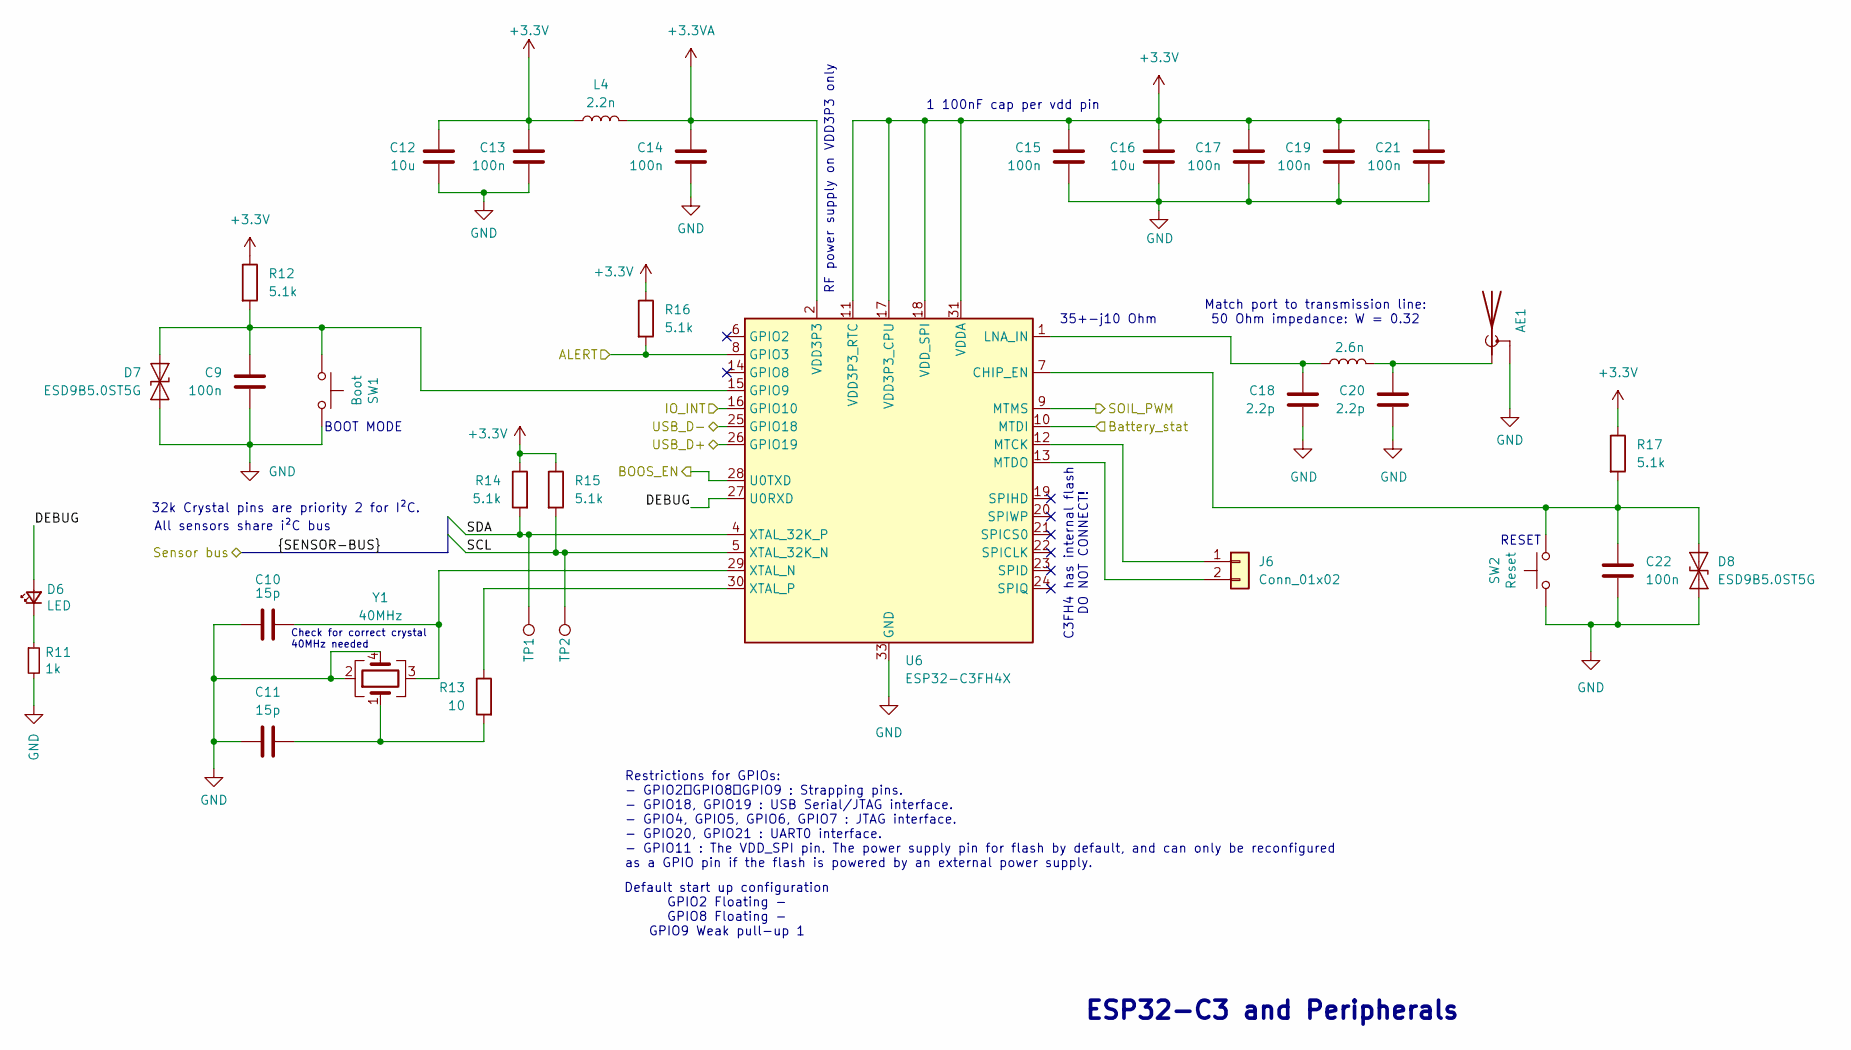
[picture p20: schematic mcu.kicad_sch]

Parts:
AE1: Antenna_Shield; Texas_SWRA117D_2.4GHz_Left
C9, C13, C14, C15, C17, C19, C21, C22: 100n; C_0402_1005Metric
C10, C11: 15p; C_0402_1005Metric
C12, C16: 10u; C_0603_1608Metric
C18, C20: 2.2p; C_0402_1005Metric
D6: LED; LED_0805_2012Metric_Pad1.15x1.40mm_HandSolder; LCSC C205445
D7, D8: ESD9B5.0ST5G; D_SOD-923
J6: Conn_01x02; PinHeader_1x02_P2.54mm_Vertical
L4: 2.2n; L_0402_1005Metric
L5: 2.6n; L_0402_1005Metric
R11: 1k; R_0402_1005Metric
R12, R14, R15, R16, R17: 5.1k; R_0402_1005Metric
R13: 10; R_0402_1005Metric
SW1: Boot; SW_Push_SPST_NO_Alps_SKRK; LCSC C115357
SW2: Reset; SW_Push_SPST_NO_Alps_SKRK; LCSC C115357
TP1, TP2: TestPoint; TestPoint_Pad_D1.0mm
U6: ESP32-C3FH4X; QFN-32-1EP_5x5mm_P0.5mm_EP3.7x3.7mm
Y1: 40MHz; Crystal_SMD_3225-4Pin_3.2x2.5mm

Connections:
+3.3V: C12.1, C13.1, C15.1, C16.1, C17.1, C19.1, C21.1, L4.2, R12.1, R14.1, R15.1, R16.1, R17.1, U6.11 (VDD3P3_RTC), U6.17 (VDD3P3_CPU), U6.18 (VDD_SPI), U6.31 (VDDA), U6.32 (VDDA); also elsewhere on the board
+3.3VA: C14.1, L4.1, U6.2 (VDD3P3), U6.3 (VDD3P3)
/ADC/ALERT: R16.2, U6.8 (GPIO3); also elsewhere on the board
/ADC/SCL: R15.2, TP2.1, U6.5 (XTAL_32K_N); also elsewhere on the board
/ADC/SDA: R14.2, TP1.1, U6.4 (XTAL_32K_P); also elsewhere on the board
/ESP_32/BOOS_EN: U6.28 (U0TXD); also elsewhere on the board
/ESP_32/Battery_stat: U6.10 (MTDI); also elsewhere on the board
/ESP_32/DEBUG: D6.2 (A), U6.27 (U0RXD)
/ESP_32/IO_INT: U6.16 (GPIO10); also elsewhere on the board
/ESP_32/SOIL_PWM: U6.9 (MTMS); also elsewhere on the board
/ESP_32/USB_D+: U6.26 (GPIO19); also elsewhere on the board
/ESP_32/USB_D-: U6.25 (GPIO18); also elsewhere on the board
GND: AE1.2 (Shield), C9.1, C10.1, C11.1, C12.2, C13.2, C14.2, C15.2, C16.2, C17.2, C18.2, C19.2, C20.2, C21.2, C22.2, D7.1 (A1), D8.1 (A1), R11.2, SW1.2, SW2.2, U6.33 (GND), Y1.2, Y1.4; also elsewhere on the board
unnamed: AE1.1 (A), C20.1, L5.1
unnamed: C11.2, R13.2, Y1.1
unnamed: D6.1 (K), R11.1
unnamed: C9.2, D7.2 (A2), R12.2, SW1.1, U6.15 (GPIO9)
unnamed: C22.1, D8.2 (A2), R17.2, SW2.1, U6.7 (CHIP_EN)
unnamed: J6.1, U6.12 (MTCK)
unnamed: J6.2, U6.13 (MTDO)
unnamed: C18.1, L5.2, U6.1 (LNA_IN)
unnamed: C10.2, U6.29 (XTAL_N), Y1.3
unnamed: R13.1, U6.30 (XTAL_P)

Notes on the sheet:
Match port to transmission line: 50 Ohm impedance: W = 0.32
32k Crystal pins are priority 2 for I²C.
RESET
ESP32-C3 and Peripherals
BOOT MODE
RF power supply on VDD3P3 only
C3FH4 has internal flash DO NOT CONNECT!
35+-j10 Ohm
Default start up configuration GPIO2 Floating - GPIO8 Floating - GPIO9 Weak pull-up 1
All sensors share i²C bus
Check for correct crystal 40MHz needed
1 100nF cap per vdd pin
Restrictions for GPIOs: - GPIO2、GPIO8、GPIO9 : Strapping pins. - GPIO18, GPIO19 : USB Serial/JTAG interface. - GPIO4, GPIO5, GPIO6, GPIO7 : JTAG interface. - GPIO20, GPIO21 : UART0 interface. - GPIO11 : The VDD_SPI pin. The power supply pin for flash by default, and can only be reconfigured as a GPI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

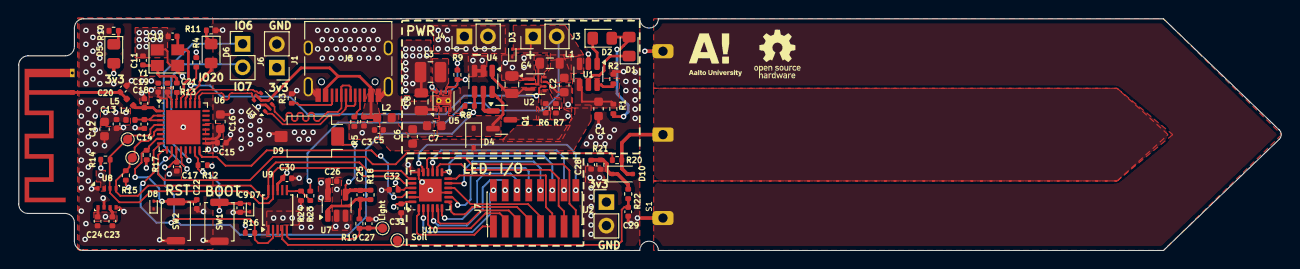
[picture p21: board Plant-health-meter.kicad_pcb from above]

Board: 4 copper layers, 136.2 x 25.0 mm, 98 parts (0 on the bottom side), 65 nets.

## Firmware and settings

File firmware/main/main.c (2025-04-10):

#include <driver/gpio.h>
#include <freertos/FreeRTOS.h>
#include <esp_wifi.h>
#include <esp_event.h>
#include <nvs_flash.h>
#include <esp_http_server.h>
#include "esp_log.h"
#include "wifi_api.h"
#include "http_server.h"
#include "firebase_api.h"
#include "io_config.h"
#include "i2c_master.h"
#include "esp_sleep.h"
#include "time_sync.h"
#include "sensor_api.h"
#include "packet.h"
#include "ble_wifi_credentials.h"
#include "data_store.h"

// Private config should include the defenitions:
// FIREBASE_HOST "xxx-rtdb.europe-west1.firebasedatabase.app"
// FIREBASE_AUTH "" // TODO: set-up firebase auth
//
// USE_HARD_CODED_CREDENTIALS (if you don't want to pair over bluetooth)
//      WIFI_SSID             (if using hard coded credentials)
//      WIFI_PASSWORD         (if using hard coded credentials)

#include "private_config.h" 
#define TAG "main"

// Wake up count in RTC memory
RTC_DATA_ATTR static int wake_count = 0;

void app_main(void) {
    wake_count++;
    ESP_LOGI(TAG, "Wake count: %d", wake_count);

    gpio_config(&io_config); 

    // Enable boost converter
    gpio_set_level(BOOST_EN, 1);
    init_wifi();


    #ifndef USE_HARD_CODED_CREDENTIALS 
        char ssid[64] = {0};
        char password[64] = {0};
        // Try loading Wi-Fi credentials from NVS
        esp_err_t creds_loaded = load_wifi_credentials(ssid, sizeof(ssid), password, sizeof(password));
        esp_err_t ret = ESP_FAIL;
    
        if (creds_loaded == ESP_OK) {
            ESP_LOGI(TAG, "Loaded credentials from NVS: SSID=%s", ssid);
            ret = connect_wifi(ssid, password);
        } else {
            ESP_LOGW(TAG, "No Wi-Fi credentials found in NVS");
        }

        // If credentials failed to load or Wi-Fi connection failed, go into BLE pairing mode
        if (ret != ESP_OK) {
            ESP_LOGW(TAG, "Wi-Fi connection failed, entering BLE mode");
            ble_wifi_start_server();
            return;
        }
    #else
        ESP_LOGI(TAG, "Using hard coded Wi-Fi credentials");
        esp_err_t ret = connect_wifi(WIFI_SSID, WIFI_PASSWORD);
        if (ret != ESP_OK) {
            ESP_LOGE(TAG, "Failed to connect to wifi");
            app_main(); // Restart main
        }

    #endif // USE_HARD_CODED_CREDENTIALS

    // Successfully connected
    esp_netif_ip_info_t ip_info;
    esp_netif_get_ip_info(esp_netif_get_handle_from_ifkey("WIFI_STA"), &ip_info);
    ESP_LOGI(TAG, "Server running on address: " IPSTR, IP2STR(&ip_info.ip));

    // Set the transmit power
    esp_err_t power_ret = esp_wifi_set_max_tx_power(60); // 8 - 84
    if (power_ret != ESP_OK) {
        ESP_LOGW(TAG, "Failed to set Wi-Fi transmit power: %s", esp_err_to_name(power_ret));
    }

    // Init REST API
    httpd_handle_t server_handle = start_webserver();

    // Init I2C driver
    ret = begin_i2c();
    if (ret != ESP_OK) {
        ESP_LOGE(TAG, "Failed to init I2C driver");
        return;
    }
    
    // Needs to be called before sensors can be used.
    init_sensors();

    // Sync time over NTP
    sync_time();

    // Fetch sensor packet and send to Firebase
    sensor_data_packet_t data_packet = get_sensor_data_packet();

    // Convert data to JSON
    char encoded_data[JSON_PACKET_LEN];
    packet_to_json(encoded_data, JSON_PACKET_LEN, &data_packet);

    // Send data to Firebase
    send_to_firebase(encoded_data);

    // Clean up and sleep
    ESP_LOGI(TAG, "Cleaning up before sleep");
    stop_webserver(server_handle);
    deinit_wifi();

    ESP_LOGI(TAG, "Entering deep sleep");
    esp_sleep_enable_timer_wakeup(60 * 1000000); // 60 seconds
    esp_deep_sleep_start();
}

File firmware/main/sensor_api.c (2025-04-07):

#include "sensor_api.h"
#include "esp_log.h"
#include "BME280.h"
#include "ADS1115.h"
#include "driver/ledc.h"

#define TAG "Sensor API"
#define MOISTURE_SENSOR_SETTLE_TIME_MS 25

static const ledc_timer_config_t pwm_timer_config = {
    .speed_mode = LEDC_LOW_SPEED_MODE,
    .duty_resolution = LEDC_TIMER_2_BIT, 
    .timer_num = LEDC_TIMER_0,
    .freq_hz = 350e3,                   //350kHz Square wave input for moisture sensor.
    .clk_cfg = LEDC_AUTO_CLK,
};

// GPIO4
static const ledc_channel_config_t moisture_sensor_channel = {
    .gpio_num = GPIO_NUM_4,
    .speed_mode = LEDC_LOW_SPEED_MODE,
    .channel = LEDC_CHANNEL_0,
    .timer_sel = LEDC_TIMER_0,
    .intr_type = LEDC_INTR_DISABLE,
    .duty = 2,
    .hpoint = 0
};

// Has to be set to 1 before sensor data can be called
static int sensor_init_status = 0;

esp_err_t init_sensors(void) {
    esp_err_t ret = ESP_OK;

    ESP_LOGI(TAG, "Initalizing PWM timer");
    ret = ledc_timer_config(&pwm_timer_config);
    if (ret != ESP_OK) {
        ESP_LOGW(TAG, "Failed to initalize PWM driver, moisture sensor will not be available.");
    }

    ret = ledc_channel_config(&moisture_sensor_channel);

    if (ret != ESP_OK) {
        ESP_LOGW(TAG, "Failed to initalize moisture sensor input channel, moisture sensor will not be available.");
    }
    
    ESP_LOGI(TAG, "Initializing sensors ...");
    // Init the BME280 temperature/humidity sensor first
    ret = init_bme280();
    if (ret != ESP_OK) {
        ESP_LOGW(TAG, "Failed to initialize BME280");
    } else {
        ESP_LOGI(TAG, "BME280 initalized succesfully");
    }

    ret = ads1115_init();
    if (ret != ESP_OK) {
        ESP_LOGW(TAG, "Failed to initalize ADS1115!");
    } else {
        ESP_LOGI(TAG, "ADS1115 initialized succesfully");
    }

    // init rest of the sensors
    sensor_init_status = 1;
    return ret;

}

static float get_temperature(void){
    if (sensor_init_status != 1) {
        ESP_LOGW(TAG, "Init sensors before calling data");
        return 0x00;
    }
    float temperature = 0.0f;
    bme280_read_temperature(&temperature);
    return temperature; // TODO. Proper conversion
}

static float get_humidity(void){
    if (sensor_init_status != 1) {
        ESP_LOGW(TAG, "Init sensors before calling data");
        return 0x00;
    }

    float humidity = 0.0f;
    bme280_read_humidity(&humidity);
    return humidity; // TODO. Proper conversion
}



// Get capacitance from voltage using polynomial regression.
// Trained using python script under /simulation: Based on LT-Spice model
static float voltage_to_capacitance(float voltage) {
    // Coefficients from the polynomial equation
    const float a0 = 4856.982050f;  
    const float a1 = -5808.710660f; 
    const float a2 = 2387.227805f; 
    const float a3 = -331.288972f;  
    
    float v1 = voltage;
    float v2 = voltage * voltage;
    float v3 = v2 * voltage;
    
    // capacitance using the polynomial
    float capacitance = a0 + (a1 * v1) + (a2 * v2) + (a3 * v3);
    return capacitance;
}

// Linearly interpolate cpacitance to moisture %, assuming linear relation ship.
static float capacitance_to_moisture_percent(float capacitance, float min_cap, float max_cap) {
    if (capacitance <= min_cap) return 0.0f;
    if (capacitance >= max_cap) return 100.0f;
    return (capacitance - min_cap) / (max_cap - min_cap) * 100.0f;
}

static float get_moisture(void) {
    if (sensor_init_status != 1) {
        ESP_LOGW(TAG, "Init sensors before calling data");
        return 0x00;
    }
    // Create input signal for moisture sensor.
    ledc_set_duty(LEDC_LOW_SPEED_MODE, moisture_sensor_channel.channel, 2);
    ledc_update_duty(LEDC_LOW_SPEED_MODE, moisture_sensor_channel.channel);
    vTaskDelay(pdMS_TO_TICKS(MOISTURE_SENSOR_SETTLE_TIME_MS));
    float capacitance = voltage_to_capacitance(read_ain0()); 
    float moisture = capacitance_to_moisture_percent(capacitance, 27.0f, 300.0f);

    // Turn off PWM signal after conversion,
    ledc_set_duty(LEDC_LOW_SPEED_MODE, moisture_sensor_channel.channel, 0);
    ledc_update_duty(LEDC_LOW_SPEED_MODE, moisture_sensor_channel.channel);
    return moisture;
}

static float voltage_to_light_level(float voltage) {
    const float Rf = 33000.0f;  // Feedback resistor (33k ohm)
    const float current_at_1mW_per_cm2 = 50.0e-6f;  // 50μA at 1mW/cm²
    float photodiode_current = voltage / Rf;
    float light_intensity = photodiode_current / current_at_1mW_per_cm2;
    return light_intensity; // mW/cm^2
}

static float get_light_level() {
    if (sensor_init_status != 1) {
        ESP_LOGW(TAG, "Init sensors before calling data");
        return 0x00;
    }
    return voltage_to_light_level(read_ain1());
}

sensor_data_packet_t get_sensor_data_packet(void){
    // Example packet, other values added later.
    sensor_data_packet_t ret = {
        .humidity = get_humidity(),
        .temperature = get_temperature(),
        .light = get_light_level(),
        .moisture = get_moisture(),
        .header = 0x00
    };
    
    // copy of generated packet
    return ret;
} 

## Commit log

2025-01-13 Adding files to remote
    [Plant-health-meter.kicad_pcb, Plant-health-meter.kicad_sch, io.kicad_sch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]
2025-01-15 Some updates
    [Plant-health-meter.kicad_sch, mcu.kicad_sch, pwr.kicad_sch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]
2025-01-16 More updates
    [Plant-health-meter.kicad_pcb, Plant-health-meter.kicad_sch, mcu.kicad_sch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]
2025-01-16 Reorganized and added simulation
    [Plant-health-meter.kicad_pcb, Plant-health-meter.kicad_sch, io.kicad_sch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]
2025-01-18 Added battery charging circuit and created WiFi api in firmware + created simple server for esp to send data to
    [Plant-health-meter.kicad_pcb, Plant-health-meter.kicad_sch, mcu.kicad_sch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]
2025-01-19 Switched to ESP-idf
2025-01-19 Improvements and Neovim works correctly now
    [Plant-health-meter.csv, pwr.kicad_sch]
2025-01-19 Added io config to main: flash led when transmitting data
2025-01-23 Updated some component packages
    [Plant-health-meter.kicad_pcb, Plant-health-meter.kicad_sch, mcu.kicad_sch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]
2025-01-30 added simple REST API for sensor data
    [Plant-health-meter.kicad_pcb, mcu.kicad_sch]
2025-02-04 Added light sensor simulation and schematic
    [Plant-health-meter.kicad_pcb, Plant-health-meter.kicad_sch, adc.kicad_sch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]
2025-02-07 Light sensor
    [Plant-health-meter.csv, Plant-health-meter.kicad_pcb, Plant-health-meter.kicad_sch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]
2025-02-13 Cleaned up
    [Plant-health-meter.kicad_pcb]
2025-02-13 removed usb port library
    [Plant-health-meter.kicad_pcb, Plant-health-meter.kicad_sch, adc.kicad_sch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]
2025-03-09 Optimized PCB lauout and added Header for LED indicator bar
    [LEDS.kicad_sch, Plant-health-meter.kicad_pcb, Plant-health-meter.kicad_sch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]
2025-03-09 Finished PCB routing and added reference designators
    [LEDS.kicad_sch, Plant-health-meter.kicad_pcb, adc.kicad_sch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]
2025-03-11 Final touches to PCB
    [LEDS.kicad_sch, Plant-health-meter.kicad_pcb, adc.kicad_sch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]
2025-03-13 ESD protection and Boost UVLO
    [Plant-health-meter-B_Cu.gbl, Plant-health-meter-B_Mask.gbs, Plant-health-meter-B_Paste.gbp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]
2025-03-14 Production files
    [LEDS.kicad_sch, Plant-health-meter.kicad_pcb, adc.kicad_sch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]
2025-03-18 i2c test code and register definitions for bme280
2025-03-19 more i2c driver code
2025-03-24 Changed packet to use floats for sensor data
2025-04-03 added driver for ADS1115
2025-04-03 Add BLE initial setup
    [partitions.csv]
2025-04-04 Change password change flow
2025-04-04 Update readme device setup instructions
2025-04-04 Add LED blinking while BLE is active
2025-04-04 Add device id parameter
2025-04-06 Calibrated all sensors
2025-04-06 Added soil moisture sensor polynomial regression script
